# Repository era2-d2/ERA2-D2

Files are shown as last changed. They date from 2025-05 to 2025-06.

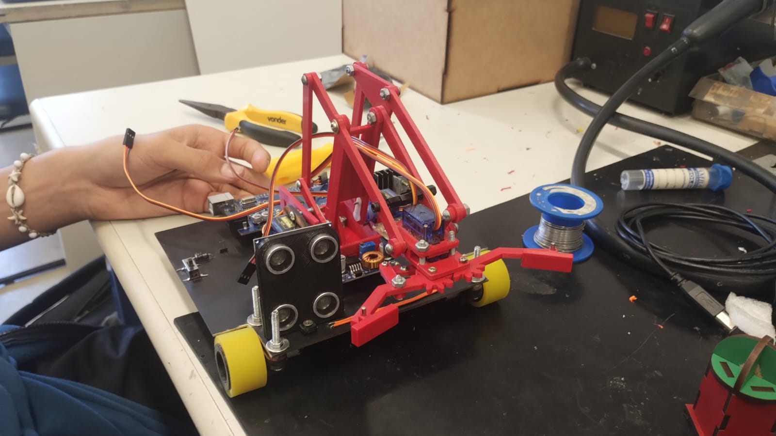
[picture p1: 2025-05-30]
Projeto/imagens/montagem.jpeg

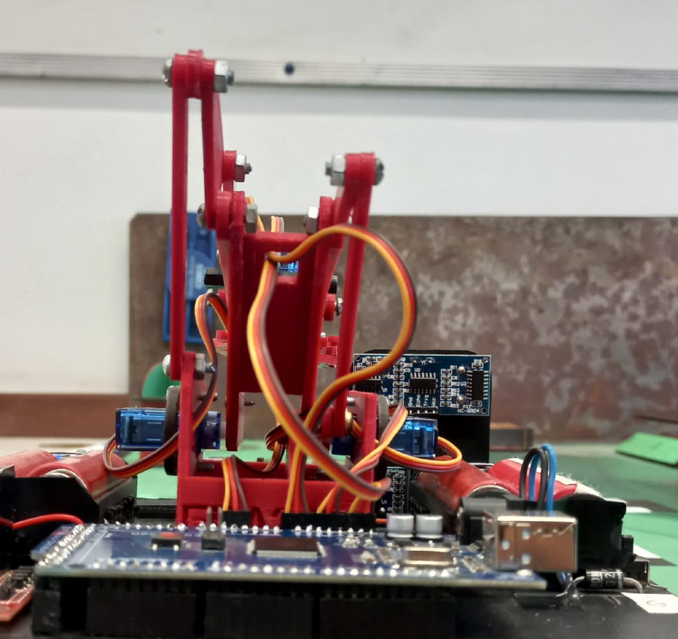
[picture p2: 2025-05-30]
Projeto/imagens/tras.jpeg

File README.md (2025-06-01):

# ERA2D2

A equipe **ERA2D2** é composta por estudantes do ensino médio do CEFET-MG, unidade Divinópolis, Minas Gerais. Desde o início de 2023, a equipe atua no âmbito do grupo **Estudos de Robótica e Automação (ERA)**, com o objetivo principal de participar da categoria High do Torneio Brasil de Robótica (TBR).

---

## Projeto Rios de Dados  
### Monitoramento em tempo real da qualidade da água

Este projeto foi desenvolvido para participação no Torneio Brasil de Robótica 2024 e tem como propósito contribuir para a preservação dos recursos hídricos e a promoção do desenvolvimento sustentável.

A plataforma criada possibilita a medição e o registro em tempo real de parâmetros essenciais da qualidade da água, tais como:

- pH  
- Turbidez  
- Níveis de oxigênio dissolvido  
- Temperatura  
- Condutividade elétrica  

Inspirada no 6º Objetivo de Desenvolvimento Sustentável das Nações Unidas (Água Potável e Saneamento), a solução emprega sensores para a coleta contínua de dados que podem ser acessados para análise e monitoramento. Tal sistema visa facilitar a tomada de decisões embasadas, o planejamento de ações corretivas e o envolvimento da comunidade local.

## Tecnologia e Engenharia

A subequipe responsável pela área de Tecnologia e Engenharia concentra seus esforços na concepção e construção de um robô autônomo capaz de atender às demandas do desafio prático proposto pelo Torneio Brasil de Robótica na categoria High (faixa etária de 15 a 19 anos).

A plataforma robótica é fundamentada em tecnologia Arduino, integrando sensores e atuadores que possibilitam o cumprimento das missões definidas pelo regulamento do TBR.

Além do desenvolvimento técnico, a equipe adota práticas colaborativas para garantir a integração eficiente das diversas áreas de conhecimento, assegurando a inovação e a eficácia dos projetos apresentados.

Essa abordagem contribui para a formação de profissionais técnicos qualificados, aptos a enfrentar desafios tecnológicos atuais e futuros, aplicando conhecimentos de forma prática e efetiva.

---

Imagens e vídeos relacionados ao projeto podem ser encontrados nas respectivas pastas do repositório.

---

## Estrutura do Projeto

O projeto está organizado da seguinte forma:

```
.
├── Mérito
│   ├── Códigos
│   ├── Impressões 3D
│   └── Monitoramento Rio Itapecerica
├── Projeto
│   ├── dados_monitoramento
│   ├── docs
│   ├── firmware
│   ├── hardware
│   └── README.md
└── Robô
├── Códigos
├── Skywalker 2.0
└── Skywalker 2.1
```

- **Mérito**: Contém códigos para as plataformas Arduino Mega e Nano, arquivos para impressões 3D e dados do monitoramento do Rio Itapecerica.  
- **Projeto**: Engloba dados do monitoramento, documentação técnica, firmware dos sistemas de monitoramento e robótico, além do hardware (modelos para impressão 3D, cortes em MDF, placas de circuito impresso, estruturas).  
- **Robô**: Abrange o desenvolvimento do robô autônomo, incluindo códigos-fonte, arquivos para fabricação e montagem, assim como versões do robô denominadas Skywalker 2.0 e 2.1.

---

## Outros Materiais

- [Tabela de Gastos](https://drive.google.com/drive/u/3/folders/1ZpHwaeWIHNITP21ojMcyqOMGcibrnDnj)
- [Relatório Sobre o Robô](https://drive.google.com/drive/u/3/folders/1UcZ1GNpwfR3S68cyZk29Z3KH6VcgLQlX)
- [Animações](https://drive.google.com/drive/folders/1Vy_ZClelRn55KMFLFU6ARa01si_wWNVY)

---

## Contato

- 🌐 Site: https://makesoft.net.br/era2d2
  
- 📧 E-mail: era2d2cefet@gmail.com

- 📷 Instagram: @era2d2

- 🎥 TikTok: @era2d2

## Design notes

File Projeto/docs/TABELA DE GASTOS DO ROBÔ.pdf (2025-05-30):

TABELAS DE GASTOS:
**Componentes referentes a sucata.
- | - | UNITÁRIO | UNITÁRIO | UNITÁRIO | UNITÁRIO
PRODUTO | QTE. | MERCADO LIVRE | ROBOCORE | ALIEXPRESS | MELHOR PREÇO
Placa de fenolite cobreada 20cm X 20cm | 1 | R$ 13,50 | - | R$ 16,21 | R$ 13,50
Sensor de distância VL53LXX-V2 | 1 | R$ 25,90 | - | R$ 8,69 | R$ 8,69
Esfera metálica de 18 mm de diâmetro | 1 | R$ 2,52 | - | R$ 3,03 | R$ 2,52
Arduino Mega 2560 | 1 | R$ 135,00 | R$ 112,10 | R$ 61,49 | R$ 61,49
Ponte H modelo L298N | 1 | R$ 11,66 | R$ 14,15 | R$ 7,41 | R$ 7,41
Módulo relé unitário 5V | 1 | R$ 11,99 | R$ 5,22 | R$ 6,99 | R$ 5,22
Regulador de tensão HW-286 | 1 | R$ 13,50 | - | R$ 13,47 | R$ 13,47
**LDR | 1 | R$ 1,06 | R$ 0,60 | R$ 0,20 | R$ 0,20
**Regulador de tensão LM7805cv | 1 | R$ 2,78 | - | R$ 0,30 | R$ 0,30
**Dissipador de calor pequeno | 1 | - | - | - | -
**Capacitor eletrolítico 0.1µF | 1 | R$ 1,13 | R$ 0,34 | R$ 0,23 | R$ 0,23

**Capacitor eletrolítico 0.33µF | 1 | R$ 0,20 | - | R$ 0,98 | R$ 0,20
**LEDs brancos de alto brilho | 2 | R$ 0,24 | R$ 0,47 | R$ 0,11 | R$ 0,11
**Chaves deslizantes | 2 | - | - | - | -
**Parafusos franceses pequenos | 2 | - | - | - | -
**Parafusos pequenos | 3 | R$ 0,08 | - | R$ 0,14 | R$ 0,08
**Espaçador sextavado | 6 | R$ 1,64 | R$ 1,42 | R$ 1,68 | R$ 1,42
**Diodos SK3G 0285 | 2 | R$ 2,21 | - | - | R$ 2,21
Motor DC N20 com caixa de redução 100/1 e encoder | 2 | - | - | R$ 45,00 | R$ 45,00
Par pneus de silicone Ø22mm | 1 | - | R$ 28,40 | - | R$ 28,40
Servomotores SG90 9 | 3 | R$ 12,21 | R$ 12,25 | R$ 6,99 | R$ 6,99
Parafusos 4 milímetros de diâmetro | 4 | R$ 0,68 | - | R$ 0,38 | R$ 0,38
Porcas 4 milímetros de diâmetro | 4 | R$ 0,68 | - | R$ 0,38 | R$ 0,38
** Baterias de lítio 18650 4.2V | 4 | R$ 29,90 | R$ 37,90 | R$ 23,23 | R$ 23,23

Tiras de velcro 73mm de comprimento | 4 | R$ 29,99 (3 metros) | - R$ 11,06 | (3 metros) | R$ 11,06
**Molas para contato de bateria | 4 | R$ 1,50 | R$ 1,58 | R$ 0,70 | R$ 0,70
Parafusos com 3 milímetros de diâmetro | 22 | R$ 0,25 | R$ 0,25 | R$ 0,15 | R$ 0,15
Porcas 3mm de diâmetro | 25 | R$ 0,25 | R$ 0,25 | R$ 0,15 | R$ 0,15
MELHOR PREÇO | 101 | - | - | - | R$ 382,87
TOTAL UTILIZANDO SUCATA | 101 | - | - | - | R$ 293,94
LOJAS | QTE. PRODUTOS (TOTAL = 28) | QTE. PEÇAS | PREÇO FINAL S/SUCATA | PREÇO FINAL C/SUCATA
MERCADO LIVRE | 23 | 93 | R$ 443,63 | R$ 297,88
ROBOCORE | 13 | 71 | R$ 376,69 | R$ 208,37
ALIEXPRESS | 23 | 93 | R$ 357,56 | R$ 249,41

PRODUTOS IMPRESSOS | QTE. | MakeSoft Solutions | PREÇO TOTAL
Garra | 1 | R$ 38,73 | R$ 38,73
Suporte para Ultrassônicos | 1 | R$ 2,19 | R$ 2,19
Suporte para Motores | 2 | R$ 0,75 | R$ 1,50
Cubo para Motores | 2 | R$ 1,95 | R$ 3,90
Suporte para Baterias | 2 | R$ 5,48 | R$ 10,96
Suporte LDR | 1 | R$ 0,68 | R$ 0,68
- | - | - | R$ 68,13

MELHOR PREÇO TOTAL FINAL S/SUCATA: R$ 440,83
MELHOR PREÇO TOTAL FINAL C/SUCATA: R$ 351,90

Considerações Finais:

Embora consideravelmente mais caras, as peças oferecidas pela Robocore e Mercado Livre são de melhor qualidade. Recomenda-se comprar a maioria das peças no Mercado Livre e, as que faltarem, na Aliexpress e Robocore. O valor final ficaria em R$474,24 com sucata e R$619,99 sem.

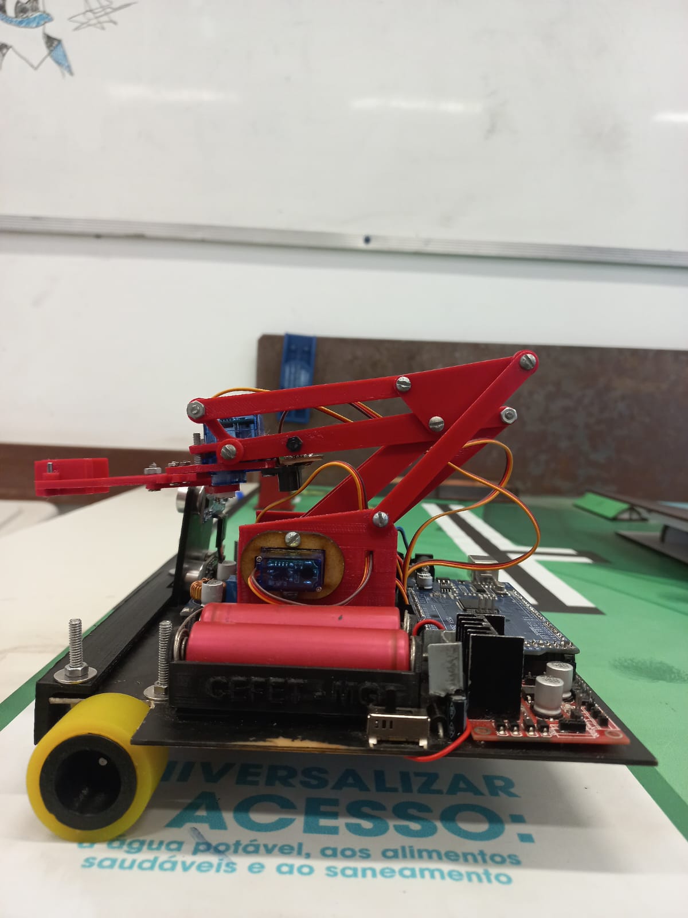
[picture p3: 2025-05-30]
Projeto/imagens/esquerda.jpeg

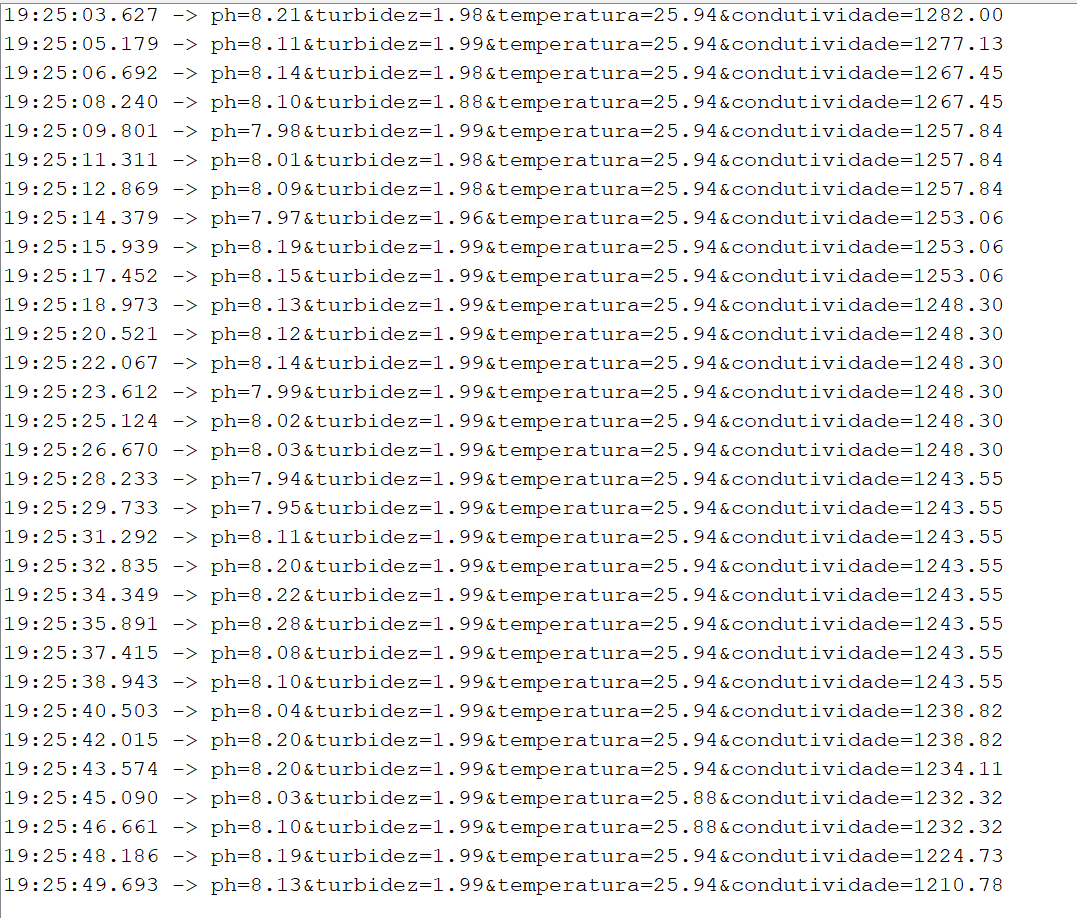
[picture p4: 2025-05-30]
Projeto/dados_monitoramento/ponto_3/Ponto 3.1.png

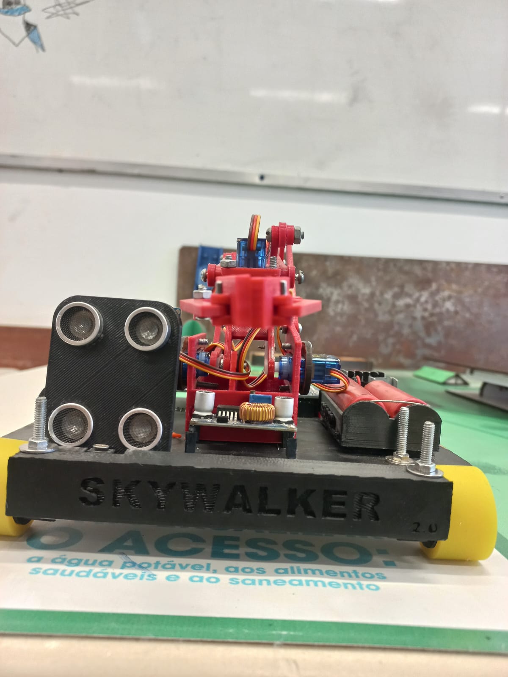
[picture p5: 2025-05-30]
Projeto/imagens/frente.jpeg

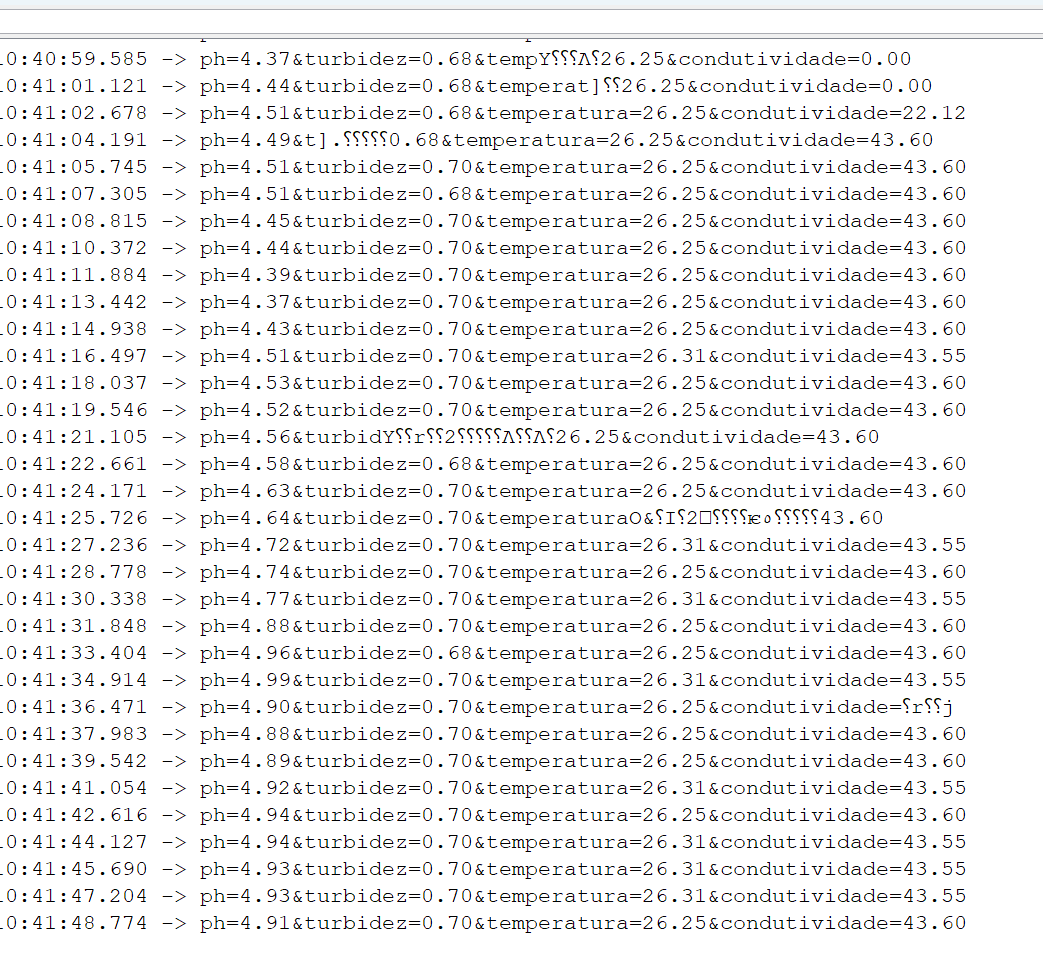
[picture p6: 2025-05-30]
Projeto/dados_monitoramento/ponto_2/Ponto 2.png

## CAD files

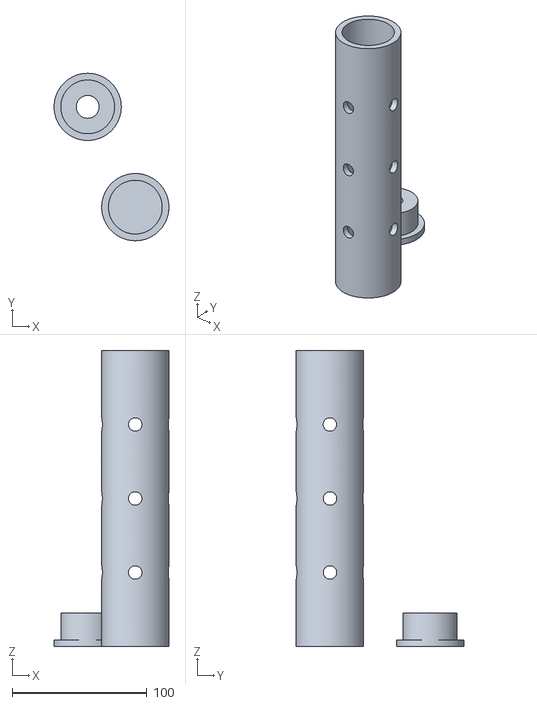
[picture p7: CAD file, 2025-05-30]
Mérito/Impressões 3D/Case - versão 1.stl
85.4 x 124.5 x 220.0

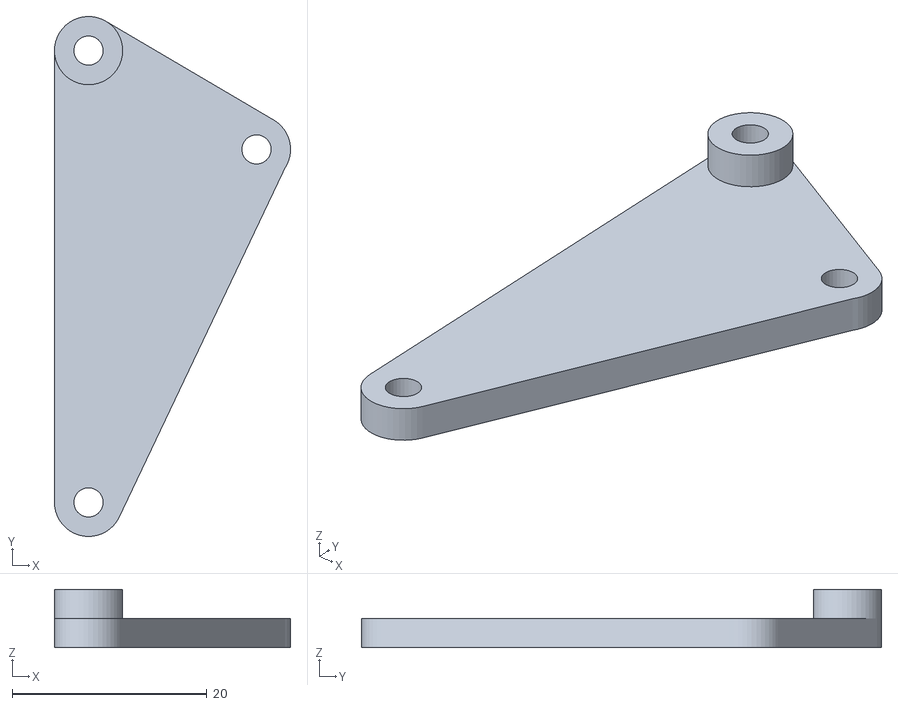
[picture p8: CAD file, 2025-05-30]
Projeto/hardware/3d_prints/robo/Braço Robótico Versão 1/Junta_01.stl
24.2 x 53.4 x 6.00

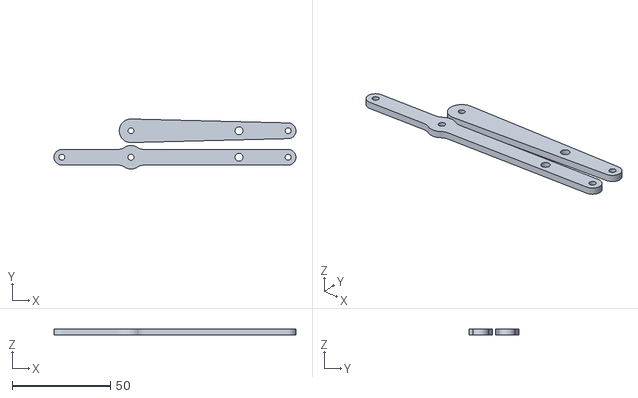
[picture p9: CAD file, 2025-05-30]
Projeto/hardware/3d_prints/robo/Garra pt2.stl
123.2 x 25.5 x 3.00

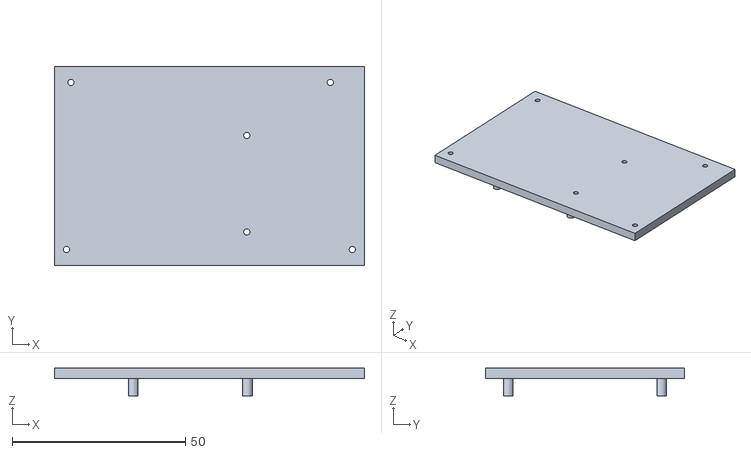
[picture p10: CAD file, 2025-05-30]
Projeto/hardware/3d_prints/robo/Impressões Diversas/Capa_ArduinoMega2560_v1.stl
89.5 x 57.3 x 8.00

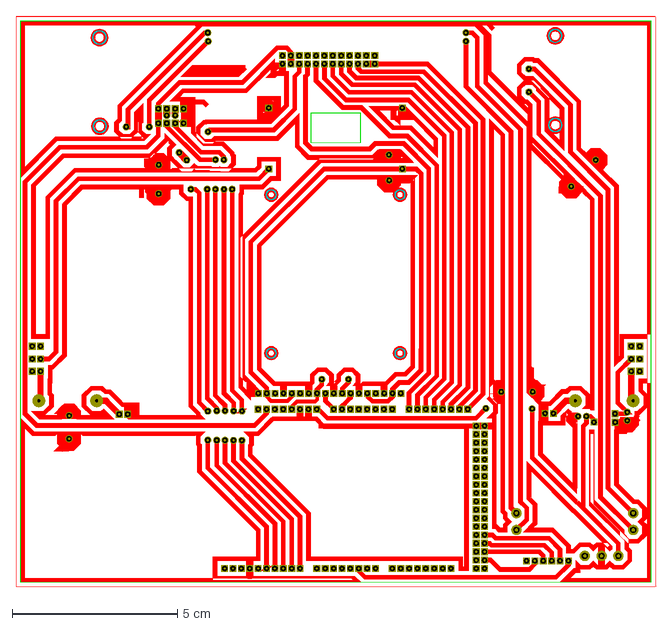
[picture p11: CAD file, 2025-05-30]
Projeto/hardware/pcb/robo/Skywalker 2.0/Estrutura Robo.DXF
19.4 x 17.3 cm

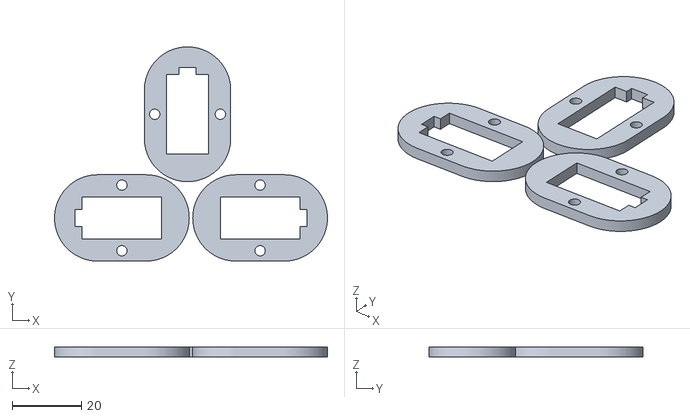
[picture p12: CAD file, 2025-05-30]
Projeto/hardware/3d_prints/robo/Braço Robótico Versão 1/Suporte_Servomotores.stl
79.0 x 62.0 x 3.00

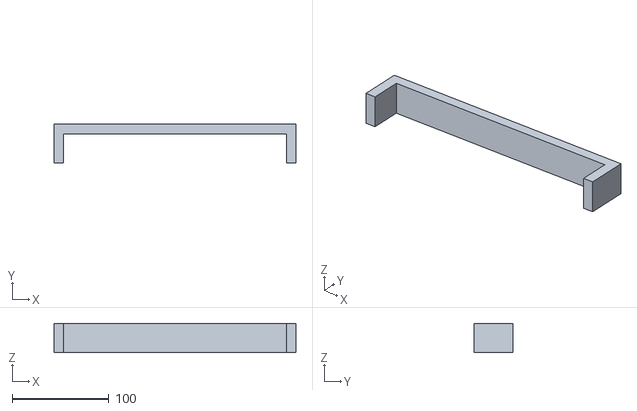
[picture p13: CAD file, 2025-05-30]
Projeto/hardware/3d_prints/robo/Impressões Diversas/Cola_Base.stl
250.0 x 40.0 x 30.0

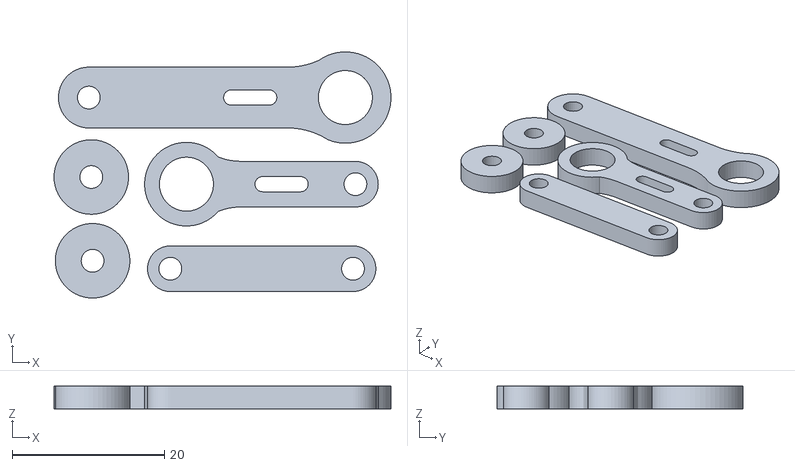
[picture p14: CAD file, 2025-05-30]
Projeto/hardware/3d_prints/robo/Braço Robótico Versão 1/Controle_Servomotores.stl
44.3 x 32.3 x 3.00

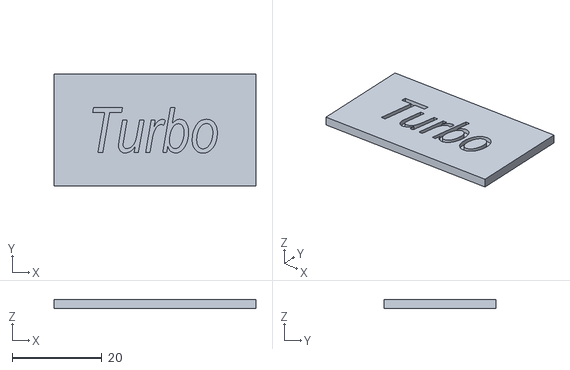
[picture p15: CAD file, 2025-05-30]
Projeto/hardware/3d_prints/robo/Impressões Diversas/TURBO.stl
45.0 x 25.0 x 2.00

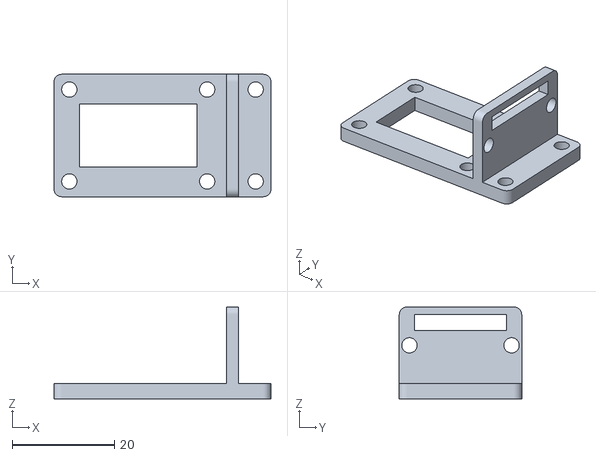
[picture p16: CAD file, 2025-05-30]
Projeto/hardware/3d_prints/robo/Braço Robótico Versão 1/Suporte_Servomotor_Garra_Inferior_Laser.stl
42.5 x 24.0 x 18.0

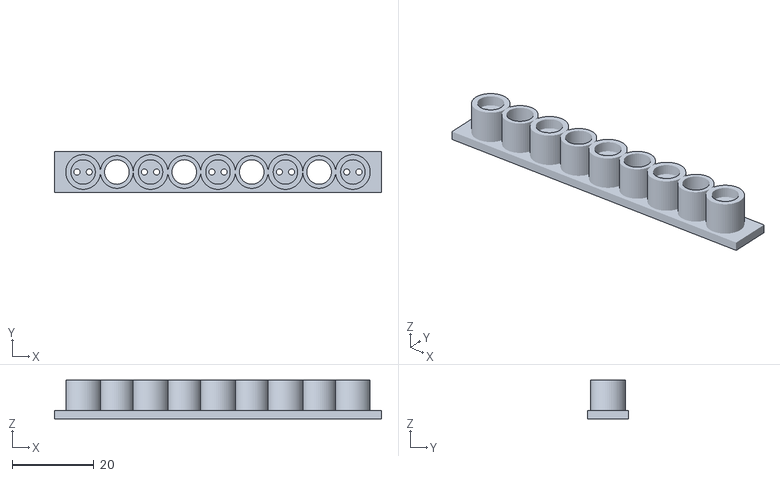
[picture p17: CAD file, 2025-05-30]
Projeto/hardware/3d_prints/robo/Impressões Diversas/Suporte_LDR_v9.stl
80.0 x 10.0 x 9.50

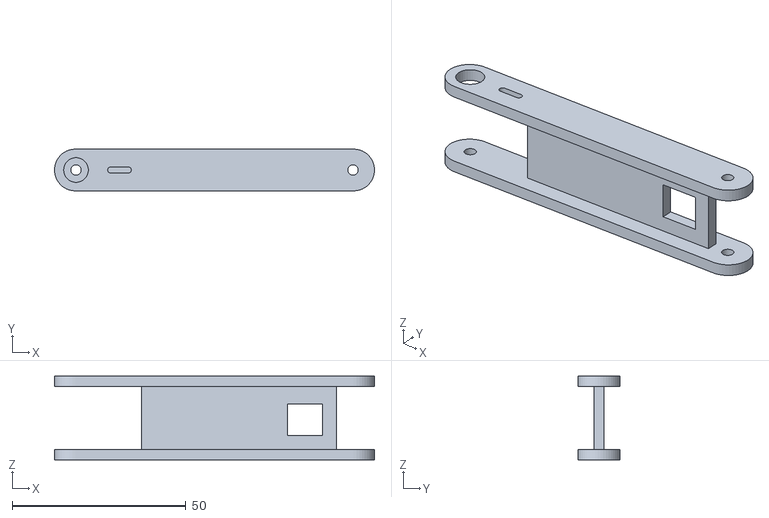
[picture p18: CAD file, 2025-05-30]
Projeto/hardware/3d_prints/robo/Braço Robótico Versão 1/Braço_Garra.stl
92.0 x 12.0 x 24.0

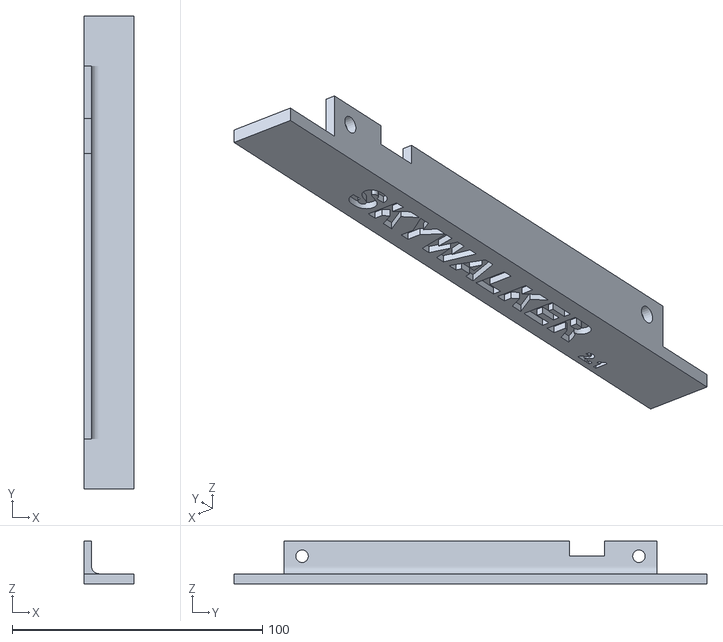
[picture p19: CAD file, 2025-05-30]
Projeto/hardware/3d_prints/robo/Impressões Diversas/SKYWALKER_2.1.stl
20.0 x 189.0 x 17.0

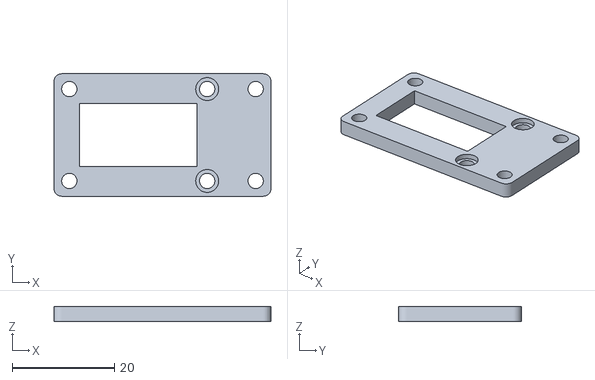
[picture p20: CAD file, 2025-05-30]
Projeto/hardware/3d_prints/robo/Braço Robótico Versão 1/Suporte_Servomotor_Garra_Inferior.stl
42.5 x 24.0 x 3.00

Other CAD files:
Projeto/hardware/3d_prints/robo/Impressões Diversas/Cola_LDR.stl
Projeto/hardware/3d_prints/robo/Braço Robótico Versão 1/Base_Garra.stl
Projeto/hardware/3d_prints/robo/Impressões Diversas/SKYWALKER_2.0.stl
Projeto/hardware/3d_prints/robo/Braço Robótico Versão 1/Garra.stl
Projeto/hardware/3d_prints/robo/Braço Robótico Versão 1/Mecanização_Braço.stl
Projeto/hardware/3d_prints/robo/Braço Robótico Versão 1/Ponta_Garra.stl
Projeto/hardware/3d_prints/robo/Braço Robótico Versão 1/Suporte_Servomotor_Garra.stl
Projeto/hardware/3d_prints/robo/Impressões Diversas/Base_Ultrassônico.stl
Projeto/hardware/3d_prints/robo/Impressões Diversas/Bolinha_v3.stl
Projeto/hardware/3d_prints/robo/Impressões Diversas/PINO.stl
Projeto/hardware/3d_prints/robo/Impressões Diversas/Suporte_Bateria.stl

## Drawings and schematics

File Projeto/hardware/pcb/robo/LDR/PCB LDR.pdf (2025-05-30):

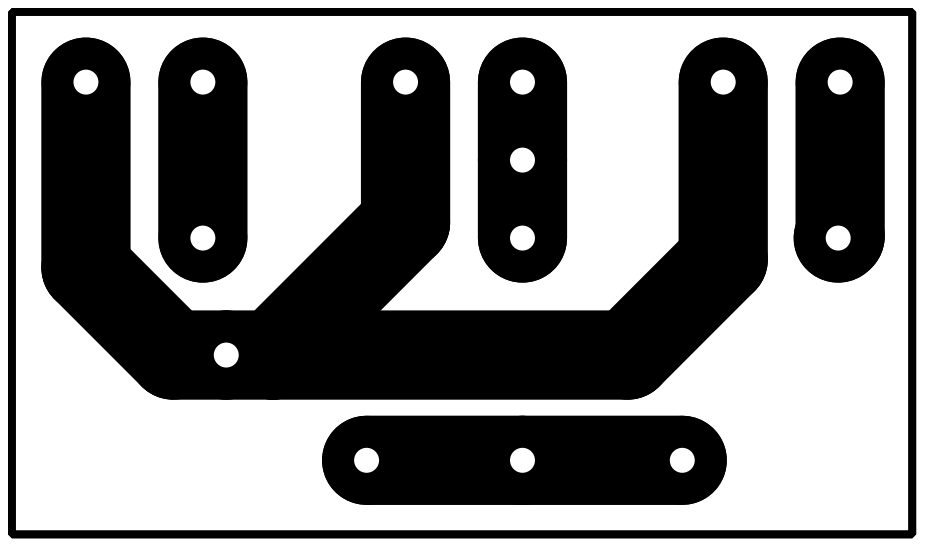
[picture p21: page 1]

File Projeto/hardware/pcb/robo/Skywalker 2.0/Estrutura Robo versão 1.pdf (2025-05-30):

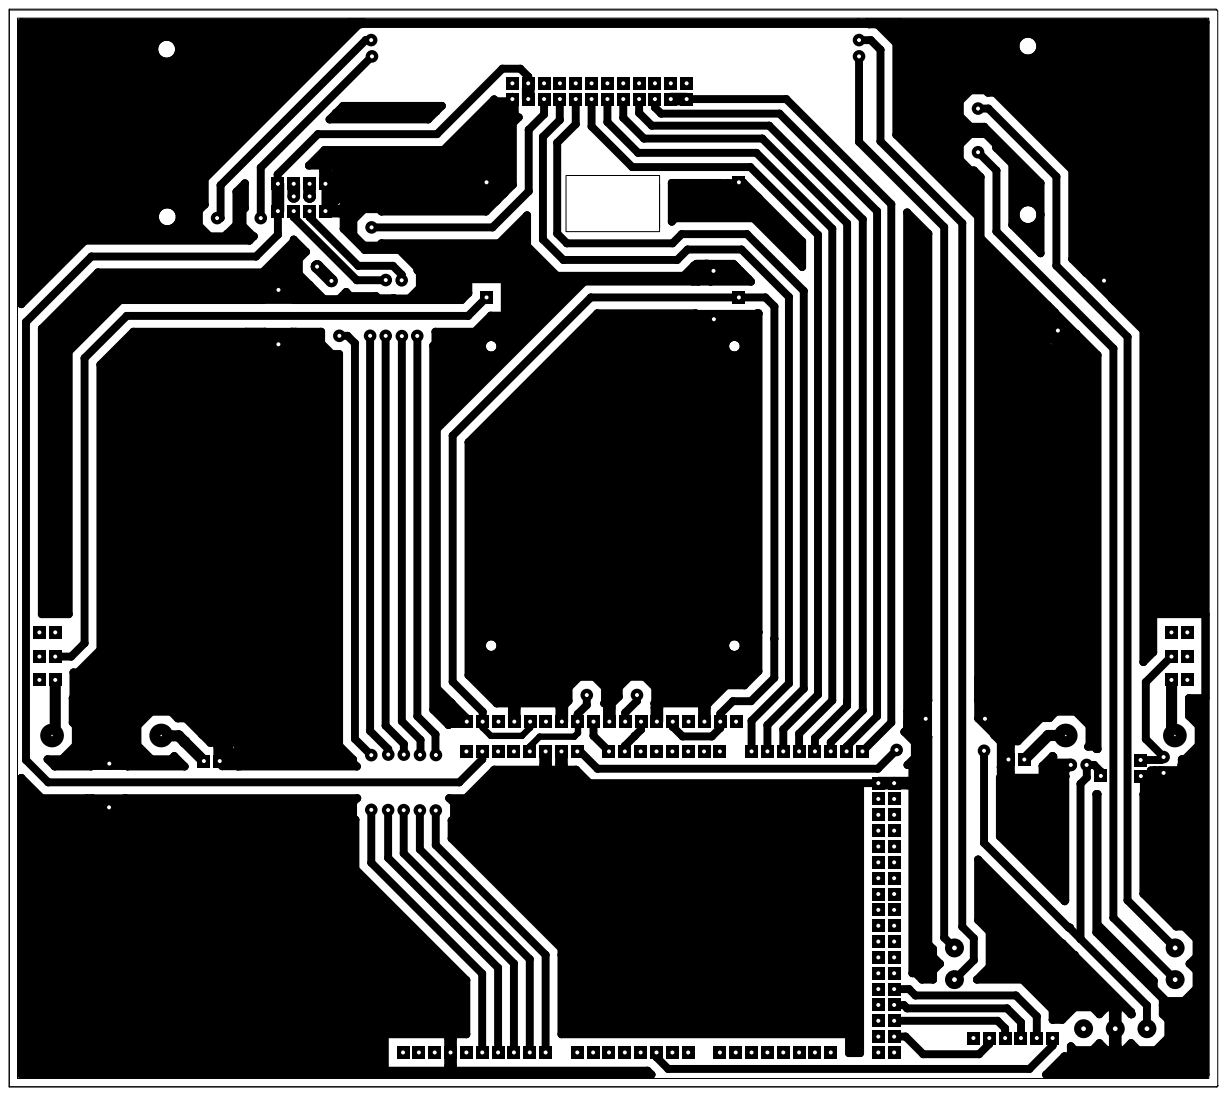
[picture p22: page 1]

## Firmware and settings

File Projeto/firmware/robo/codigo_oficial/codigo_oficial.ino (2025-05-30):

// Bibliotecas.
#include <VL53L0X.h>
#include <EEPROM.h>
#include <HCSR04.h>
#include <Servo.h>
#include <Wire.h>
//#include <StarWars.h>

// Motores.
#define mEa 29
#define mEb 27
#define mDa 25
#define mDb 23
#define mEv 2
#define mDv 3

// Constantes.
#define tempoDir 8.1111 // original 8.1111   //02-08: 7.73  // 07-08: 7.72  // 09-08: 8.36
#define tempoEsq 8.3625 // original 8.3625   //02-08: 8.005  // 07-08: 8.36  // 09-08: 7.95
#define tempoReto 0.01890359

#define velE 240
#define velD 255

#define porcentagemMotor 1.1
#define porcentagemEsquerda 1.03
#define porcentagemDireita 1.06
#define debug 1.02

// Sensor de cor.
#define sc A0
bool CORPRETA;
bool leituraCorPreta;
byte contagemDerrubados = 0;

// Mínimos e Máximos de leitura da cor vermelha.
int CORVERMELHAMin = 4 * EEPROM.read(5);
int CORVERMELHAMax = 4 * EEPROM.read(6);

// Calibração de cores.
#define PRETO 1
#define BRANCO 0

// Garra.
Servo servo1; // 60 a 140 graus  - graus, mais pra tras
Servo servo2; // 50 a 140 graus  - graus, mais alto
Servo servo3; // 180 a 90 graus  - graus, garra fechada

byte i = 0;

// Laser.
VL53L0X laser;
unsigned long distanciaLaser;

// Ultrassônico.
#define trig1 11
#define trig2 10
#define echo1 8
#define echo2 9

UltraSonicDistanceSensor us1(trig1, echo1); // (Trig, Echo)
UltraSonicDistanceSensor us2(trig2, echo2);

unsigned long distancia1;
unsigned long distancia2;

bool arvoreP = false;
bool arvoreG = false;

// Funções dos Motores.
void Para(int para)
{

    digitalWrite(mEa, LOW);
    digitalWrite(mEb, LOW);
    analogWrite(mEv, 0);
    digitalWrite(mDa, LOW);
    digitalWrite(mDb, LOW);
    analogWrite(mDv, 0);
    delay(para);
}

// Tempo.
float Distancia(float distancia)
{
    distancia = (float)(distancia * 1.0238 + 0.486);
    float tempo = (float)(distancia / tempoReto);
    return tempo;
}

void Direcao(float tempo, bool frente = true)
{

    bool a = frente ? true : false;
    bool b = frente ? false : true;

    digitalWrite(mEa, a);
    digitalWrite(mEb, b);
    analogWrite(mEv, velE);

    digitalWrite(mDa, a);
    digitalWrite(mDb, b);
    analogWrite(mDv, velD);
    delay(tempo * porcentagemMotor);
    Para(100);
}

void Gira(float angulo, bool esquerda = true)
{

    bool a = esquerda ? false : true;
    bool b = esquerda ? true : false;
    float tempo = esquerda ? (angulo * tempoEsq * porcentagemEsquerda) : (angulo * tempoDir * porcentagemDireita);

    digitalWrite(mEa, a);
    digitalWrite(mEb, b);
    analogWrite(mEv, velE);

    digitalWrite(mDa, b);
    digitalWrite(mDb, a);
    analogWrite(mDv, velD);
    delay(tempo);
    Para(100);
}

// Funções Sensor de Cor.
void SensorCor()
{
    if (analogRead(sc) > CORVERMELHAMax)
    {
        CORPRETA = 1;
    }
    else
    {
        CORPRETA = 0;
    }
}

void SensorCorAux()
{
    if (analogRead(sc) > CORVERMELHAMax)
    {
        leituraCorPreta = 1;
    }
    else
    {
        leituraCorPreta = 0;
    }
}

// Garra.
void Inicial()
{
    int v1 = servo1.read();
    int v2 = servo2.read();

    // Ajusta o servo1 para 145º.
    if (v1 < 145)
    {
        for (int i = v1; i <= 145; i++)
        {
            servo1.write(i);
            delay(12);
        }
    }
    else if (v1 > 145)
    {
        for (int i = v1; i >= 145; i--)
        {
            servo1.write(i);
            delay(12);
        }
    }

    // Ajusta o servo2 para 70º.
    if (v2 < 70)
    {
        for (int i = v2; i <= 70; i++)
        {
            servo2.write(i);
            delay(12);
        }
    }
    else if (v2 > 70)
    {
        for (int i = v2; i >= 70; i--)
        {
            servo2.write(i);
            delay(12);
        }
    }

    servo3.write(180);
}

void ArvoreGrande()
{
    for (i = 145; i >= 45; i--)
    { // Servo1: 35 para a árvore pequena e 55 para a árvore grande.
        servo1.write(i);
        delay(12);
    }

    for (i = 70; i <= 130; i++)
    {
        servo2.write(i);
        delay(12);
    }
}

void ArvorePequena()
{
    for (i = 145; i >= 30; i--)
    { // Servo1: 35 para a árvore pequena e 55 para a árvore grande.
        servo1.write(i);
        delay(12);
    }

    for (i = 70; i <= 130; i++)
    {
        servo2.write(i);
        delay(12);
        // Não fique torto por favor, te amamos por isso ❤.
    }
}

// Laser.
bool Laser()
{
  distanciaLaser = laser.readRangeContinuousMillimeters() - 25; // 25 é o erro do sensor.
  distanciaLaser < 100 ? arvoreG = 1 : arvoreG = 0;
}

// Ultrassônico.
bool Ultrassonico()
{
    // distancia1 = us1.measureDistanceCm();
    distancia2 = us2.measureDistanceCm();

    if (distancia2 < 10.0)
    {
        arvoreG = true;
    }
    else
    {
        arvoreG = false;
    }
    return arvoreG;
}

// Missão da Cor.
void Turbo(int tempo)
{

    digitalWrite(4, LOW);
    digitalWrite(mEa, HIGH);
    digitalWrite(mEb, LOW);
    analogWrite(mEv, velE);
    digitalWrite(mDa, HIGH);
    digitalWrite(mDb, LOW);
    analogWrite(mDv, velD);
    delay(tempo);
    digitalWrite(4, HIGH);
}

void Rampa(int tempo)
{

    for (i = 145; i >= 48; i--)
    { // Servo1: 35 para a árvore pequena e 55 para a árvore grande.
        servo1.write(i);
        delay(12);
    }

    for (i = 70; i >= 65; i--)
    { // Servo1: 35 para a árvore pequena e 55 para a árvore grande.
        servo2.write(i);
        delay(12);
    }

    servo3.write(85);

    Turbo(tempo);

    tempo = 2000;

    for (i = 48; i >= 20; i--)
    { // Servo1: 35 para a árvore pequena e 55 para a árvore grande.
        servo1.write(i);
        delay(12);

        Turbo(tempo);
        break;
    }
}

void AbaixaRampa()
{

    for (i = 145; i >= 70; i--)
    {
        servo1.write(i);
        delay(12);
    }

    for (i = 70; i <= 180; i++)
    {
        servo2.write(i);
        delay(12);
    }

    for (i = 70; i >= 50; i--)
    {
        servo1.write(i);
        delay(12);
    }
}

void Cor()
{

    for (i = 30; i <= 60; i++)
    {
        servo1.write(i);
        delay(12);
    }
    servo2.write(65);
}

void setup()
{

    // Motores.
    pinMode(mEa, OUTPUT);
    pinMode(mEb, OUTPUT);
    pinMode(mDa, OUTPUT);
    pinMode(mDb, OUTPUT);
    pinMode(mEv, OUTPUT);
    pinMode(mDv, OUTPUT);
    pinMode(4, OUTPUT);

    // Sensor de Cor.
    pinMode(sc, INPUT);

    // Servomotores.
    servo1.attach(5);
    servo2.attach(6);
    servo3.attach(7);

    // Ultrassônicos.
    pinMode(trig1, OUTPUT);
    pinMode(trig2, OUTPUT);
    pinMode(echo1, INPUT);
    pinMode(echo2, INPUT);

    // Inicializações.
    digitalWrite(4, HIGH);
    Inicial();

    // StarWars Theme
    // ImperialMarch march(45, 108);

    // Laser.
//    Wire.begin();
//    
//    laser.setTimeout(500);
//    
//    if (!laser.init()) while (true);
//
//    // Inicia o modo contínuo consecutivo (Lê o mais rápido possível).
//    laser.startContinuous();
  
    //Para usar o modo de tempo contínuo, forneça um período entre as medições em millissegundos laser.startContinuous(100).
}

void loop()
{

    // Primeira parte.

    Gira(90 * debug);         // Esquerda
    Direcao(Distancia(53.5)); // Frente
    Gira(90);                 // Esquerda
    Direcao(Distancia(11.5)); // Frente

    if (Ultrassonico())
    {

        Direcao(Distancia(12), false); // Trás
        Gira(90, false);               // Direita
        Direcao(Distancia(6));         // Frente
        Gira(90);                      // Esquerda
        ArvoreGrande();                // ARVORE GRANDE.
        Direcao(Distancia(6.5));       // Frente

        for (i = 180; i >= 80; i--)
        {
            servo3.write(i);
            delay(12);
        }

        for (i = 45; i <= 110; i++)
        {
            servo1.write(i);
            delay(12);
        }

        for (i = 130; i >= 90; i--)
        {
            servo2.write(i);
            delay(12);
        }

        Direcao(Distancia(6), false); // Trás
        Gira(90, false);              // Direita
        Direcao(Distancia(5));        // Frente
        Gira(90, false);              // Direita
        Direcao(Distancia(5.5));      // Frente
        Gira(91);                     // Esquerda
        Direcao(Distancia(16));       // Frente

        for (i = 110; i <= 120; i++)
        {
            servo1.write(i);
            delay(12);
        }

        servo3.write(180);

        // Pegar próxima árvore.

        Direcao(Distancia(8), false); // Trás
        Gira(90);                     // Esquerda
        Direcao(Distancia(18));       // Frente
        Gira(20, false);              // Direita

        for (i = 90; i <= 135; i++)
        {
            servo2.write(i);
            delay(12);
        }

        for (i = 110; i >= 32; i--)
        {
            servo1.write(i);
            delay(12);
        }

        for (i = 180; i >= 80; i--)
        {
            servo3.write(i);
            delay(8);
        }

        for (i = 32; i <= 115; i++)
        {
            servo1.write(i);
            delay(12);
        }

        Direcao(Distancia(4), false); // Trás
        Gira(60, false);              // Direita
        Direcao(Distancia(16));       // Frente
        servo3.write(180);

        // Árvore pequena.
    }
    else
    {

        Direcao(Distancia(12), false); // Trás
        Gira(90, false);               // Direita
        Direcao(Distancia(6));         // Frente
        Gira(90);                      // Esquerda
        ArvorePequena();
        Direcao(Distancia(6)); // Frente

        for (i = 180; i >= 80; i--)
        {
            servo3.write(i);
            delay(12);
        }

        for (i = 45; i <= 100; i++)
        {
            servo1.write(i);
            delay(12);
        }

        servo1.write(100);

        Direcao(Distancia(4), false); // Trás
        Gira(90, false);              // Direita
        Direcao(Distancia(20));       // Frente

        for (i = 120; i <= 120; i++)
        {
            servo1.write(i);
            delay(12);
        }

        for (i = 130; i <= 130; i++)
        {
            servo2.write(i);
            delay(12);
        }

        servo3.write(180);

        // Pegar próxima árvore.
        Direcao(Distancia(8.5), false); // Trás
        Gira(60);                       // Esquerda

        for (i = 130; i >= 100; i--)
        {
            servo2.write(i);
            delay(12);
        }

        for (i = 120; i >= 45; i--)
        {
            servo1.write(i);
            delay(12);
        }

        Direcao(Distancia(8)); // Frente

        for (i = 180; i >= 80; i--)
        {
            servo3.write(i);
            delay(8);
        }

        for (i = 45; i <= 110; i++)
        {
            servo1.write(i);
            delay(12);
        }

        for (i = 100; i >= 55; i--)
        {
            servo2.write(i);
            delay(12);
        }

        Direcao(Distancia(9), false); // Trás
        Gira(60, false);              // Direita
        Direcao(Distancia(3));        // Frente
        Gira(90, false);              // Direita
        Direcao(Distancia(8));        // Frente
        Gira(90);                     // Esquerda
        Direcao(Distancia(14));       // Frente

        for (i = 60; i <= 110; i++)
        {
            servo2.write(i);
            delay(12);
        }

        for (i = 110; i >= 105; i--)
        {
            servo1.write(i);
            delay(12);
        }

        servo3.write(180);
        Direcao(Distancia(8), false);  // Trás
        Gira(89, false);               // Direita
        Direcao(Distancia(19), false); // Trás
        Gira(92);                      // Esquerda
    }

    Direcao(Distancia(62), false); // Trás
    // march.playMelody();
    delay(120000);

    // SEGUNDA MISSÃO

    Direcao(Distancia(34.2)); // Frente
    Gira(92, false);          // Direita
    Direcao(Distancia(20));   // Frente
    Rampa(650);
    Gira(3);                // Esquerda
    Direcao(Distancia(35)); // Frente

    Cor();
    SensorCor();

    for (i = 60; i <= 80; i++)
    {
        servo1.write(i);
        delay(10);
    }

    for (i = 65; i >= 55; i--)
    {
        servo2.write(i);
        delay(10);
    }

    for (i = 180; i >= 90; i--)
    {
        servo3.write(i);
        delay(5);
    }

    Direcao(Distancia(32), false); // Trás
    Gira(88.5, false);             // Direita
    Direcao(Distancia(32));        // Frente

    for (int y = 0; y < 4; y++)
    {

        SensorCorAux();

        if (leituraCorPreta == CORPRETA)
        {

            if (contagemDerrubados == 4)
            {
                break;
            }

            // Alteramos durante o ensaio
            Direcao(Distancia(10), false); // Trás
            Gira(35, false);               // Direita

            for (i = 80; i >= 40; i--)
            {
                servo1.write(i);
                delay(10);
            }

            Gira(40); // Esquerda
            contagemDerrubados++;

            for (i = 40; i <= 80; i++)
            {
                servo1.write(i);
                delay(10);
            }

            if (y == 3)
            {
                break;
            }
        }
        else
        {

            if (y == 3)
            {
                break;
            }
            Direcao(Distancia(10), false); // Trás
        }

        if (contagemDerrubados >= 4)
        {
            break;
        }

        Gira(94);                 // Esquerda
        Direcao(Distancia(25.5)); // Frente
        Gira(90, false);          // Direita
        Direcao(Distancia(11.2)); // Frente
    }

    if (contagemDerrubados < 4)
    {

        if (leituraCorPreta == CORPRETA)
        {
            Direcao(Distancia(18), false); // Trás
        }
        else
        {
            Direcao(Distancia(25), false); // Trás
        }

        Gira(89, false);        // Direita
        Direcao(Distancia(40)); // Frente

        // Outro lado (otherside).
        Direcao(Distancia(27), false); // Trás
        Gira(90, false);               // Direita
        Direcao(Distancia(33));        // Frente

        for (int y = 0; y < 4; y++)
        {

            if (contagemDerrubados == 4)
            {
                break;
            }

            SensorCorAux();

            if (leituraCorPreta == CORPRETA)
            {

                if (contagemDerrubados == 4)
                {
                    break;
                }

                Direcao(Distancia(9), false); // Trás
                Gira(40);                     // Esquerda

                for (i = 80; i >= 40; i--)
                {
                    servo1.write(i);
                    delay(10);
                }

                Gira(35, false); // Direita
                contagemDerrubados++;

                for (i = 40; i <= 80; i++)
                {
                    servo1.write(i);
                    delay(10);
                }

                if (y == 3)
                {
                    break;
                }
            }
            else
            {

                if (y == 3)
                {
                    break;
                }

                Direcao(Distancia(10), false); // Trás
            }

            if (contagemDerrubados >= 4)
            {
                break;
            }

            Gira(95);                 // Esquerda
            Direcao(Distancia(26.8)); // Frente
            Gira(89, false);          // Direita
            Direcao(Distancia(12));   // Frente
        }
    }
    else
    {
        // march.playMelody();
        delay(1000000);
    }
    // march.playMelody();
    delay(1000000);
}

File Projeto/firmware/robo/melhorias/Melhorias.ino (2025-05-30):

// Bibliotecas.
//#include <StarWars.h> // Música StarWars.
#include <VL53L0X.h>  // Sensor Laser.
#include <EEPROM.h>   // Memória EEPROM.
#include <HCSR04.h>   // Ultrassônico.
#include <Servo.h>    // Servomotores.
#include <Wire.h>     // Protocolo I2C.

// Pinos dos Motores.
#define mEa 29 // Pino Digital.
#define mEb 27 // Pino Digital.
#define mDa 25 // Pino Digital.
#define mDb 23 // Pino Digital.
#define mEv 2  // Pino Digital PWM.
#define mDv 3  // Pino Digital PWM.

// Pinos dos Encoders.
#define pinAD 18 // Canal A.
#define pinAE 19 // Canal A.
//#define pinBD  // Canal B.
//#define pinBD  // Canal B.

// Constantes dos Motores.
#define velE 255 // 100% de velocidade no Motor Esquerdo.
#define velD 217 // 85% de velocidade no Motor Direito.
const float debugEnc = 0.968; // Erro do encoder. Aumentar o valor (> 0.9) vai pra esquerda.
// ❤☺

const double perimetro = 10.68141502; // Perímetro da roda.
const double circunferencia = 54.35393641; // Circuinferência do robô (diâmetro = distância entre eixo das rodas).

// Parâmetros PID.
const double Kp = 5.8;  // 6    Constante Proporcional.
const double Ki = 0.6;  // 0.6  Constante Integrativa.
const double Kd = 0.7;  // 0.75 Constante Derivativa.
const double Tm = 0.03; // 0.03 // Tempo de amostragem média entre leituras.

double erro, erro1 = 0, erro2 = 0;
double PWME, PWMD, PWME1 = velE, PWMD1 = velD;

double distanciaE = 0, distanciaD = 0, distanciaT = 0;
unsigned long primeiroMillis;

volatile long pulsosE = 0, pulsosD = 0;

// Dados importantes
const float distanciaPoluentes = 25.5; // Valor arbitário, é necessário alterá-lo
int numPoluente = 0;

//---------------------------------------------------------------------------------ENCODER-------------------------------------------------------------------------------//
void ContadorEsq() {
  pulsosE++;
}
void ContadorDir() {
  pulsosD++;
}
void PIDEncoder() {

  if ((millis() - primeiroMillis) >= (Tm * 1000)) {
    noInterrupts();
    distanciaE = (double)(perimetro * pulsosE * debugEnc) / 1400;
    distanciaD = (double)(perimetro * pulsosD) / 1400;
    distanciaT = distanciaT + (double)(perimetro * pulsosE) / 1400;
    interrupts();

    pulsosD = pulsosE = 0;
    primeiroMillis = millis();
  }

  erro = distanciaD - distanciaE;

  //---------SATURAR PWM DE ENTRADA----------//
  if (PWME1 > 255) PWME1 = 255;
  if (PWME1 < 110) PWME1 = 110;

  if (PWMD1 > 255) PWMD1 = 255;
  if (PWMD1 < 110) PWMD1 = 110;

  //--------------CALCULO PID----------------//
  PWME = PWME1 + (double)((Kp + Kd / Tm) * erro + (Ki * Tm - 2 * Kd / Tm) * erro1 + (Kd / Tm) * erro2); // Retirou-se -Kp de (-Kp + Ki*Tm -2*Kd/Tm).
  PWMD = PWMD1 + (double)((Kp + Kd / Tm) * (-1 * erro) + (Ki * Tm - 2 * Kd / Tm) * (-1 * erro1) + (Kd / Tm) * (-1 * erro2)); // O erro direito é sempre o oposto do esquerdo.
  PWME1 = PWME;
  PWMD1 = PWMD;
  erro2 = erro1;
  erro1 = erro;

  //----------SATURAR PWM DE SAÍDA-----------//
  if (PWME > 255) PWME = 255;
  if (PWME < 110) PWME = 110;

  if (PWMD > 255) PWMD = 255;
  if (PWMD < 110) PWMD = 110;

  //------------COMANDO MOTORES--------------//
  analogWrite(mEv, PWME);
  analogWrite(mDv, PWMD);
}

//----------------------------------------------------------------------------------GARRA--------------------------------------------------------------------------------//
Servo servo1; // 30 a 145 graus  - graus, mais pra tras.
Servo servo2; // 50 a 140 graus  - graus, mais alto.
Servo servo3; // 180 a 85 graus  - graus, garra fechada.

byte ultimoEstadoX = 0, ultimoEstadoY = 0, ultimoEstadoGarra;

// Funções da Garra.
void Garra(int x, int y, bool fechada = false) {
  if (x <= 30) x = 30;
  if (x >= 145) x = 145;

  // Servo1.
  if (ultimoEstadoX > x) {
    for (byte i = ultimoEstadoX; i >= x; i--) {
      servo1.write(i);
      delay(10);
    }
  } else if (ultimoEstadoX < x) {
    for (byte i = ultimoEstadoX; i <= x; i++) {
      servo1.write(i);
      delay(10);
    }
  }

  // Servo2.
  if (ultimoEstadoY > y) {
    for (byte i = ultimoEstadoY; i >= y; i--) {
      servo2.write(i);
      delay(12);
    }
  } else if (ultimoEstadoY < y) {
    for (byte i = ultimoEstadoY; i <= y; i++) {
      servo2.write(i);
      delay(12);
    }
  }

  // Servo3.
  if (fechada == true) {
    if (ultimoEstadoGarra = true) ultimoEstadoGarra = 90;
    for (byte i = ultimoEstadoGarra; i >= 90; i--) {
      servo3.write(i);
      delay(10);
    }
  }
  else  servo3.write(180);
  ultimoEstadoGarra = fechada;
  ultimoEstadoX = x;
  ultimoEstadoY = y;
}

void Inicial() {
  ultimoEstadoX = servo1.read();
  ultimoEstadoY = servo2.read();

  Garra(145, 70); // Posição inicial: Servo1 em 145º e Servo2 em 60º, garra aberta.
}

void LerArvore() {
  Garra(90, 110);  // Altura ideal para fazer a leitura das alturas das árvores.
}
void ArvoreGrande() {
  Garra(70, 135);  // Altura ideal para pegar a árvore grande.
}
void ArvorePequena() {
  Garra(60, 130);  // Altura ideal para pegar a árvore pequena.
}

//------------------------------------------------------------------------------SENSOR DE COR----------------------------------------------------------------------------//
#define sc A0 // Pino do Sensor de Cor.

bool CORPRETA;
bool leituraCorPreta;
int contagemDerrubados = 0;

// Mínimos e Máximos de leitura da cor vermelha.
unsigned int CORVERMELHAMin;
unsigned int CORVERMELHAMax;

// Funções Sensor de Cor.
void SensorCor() {
  if (analogRead(sc) > CORVERMELHAMax) CORPRETA = 1;
  else CORPRETA = 0;
}

void SensorCorAux() {
  if (analogRead(sc) > CORVERMELHAMax) leituraCorPreta = 1;
  else leituraCorPreta = 0;
}

//----------------------------------------------------------------------------------LASER--------------------------------------------------------------------------------//
float distanciaUs1 = 0;   // Armazena a leitura de distância do Ultrassônico 1.
float distanciaUs2 = 0;   // Armazena a leitura de distância do Ultrassônico 2.
float distanciaLaser = 0; // Armazena a leitura de distância do Laser.

bool arvoreG; // Árvore Grande, verdadeira ou falsa.

VL53L0X laser; // Declara o Laser 1.

// Função do Laser.
bool Laser() {

  distanciaLaser = (laser.readRangeContinuousMillimeters() - 20); // 20 é o erro do sensor.

  if (distanciaLaser <= 130.0) arvoreG = true;
  else arvoreG = false;

  Serial.print(distanciaLaser);
  Serial.print("     ");
  Serial.println(arvoreG);

  return arvoreG;
}

//------------------------------------------------------------------------------ULTRASSÔNICO-----------------------------------------------------------------------------//
// Pinos dos Ultrassônicos.
#define trig1 11 // Pino Digital.
#define trig2 10 // Pino Digital.
#define echo1 8  // Pino Digital.
#define echo2 9  // Pino Digital.

UltraSonicDistanceSensor us1(trig1, echo1); // Declara o Ultrassônico 1.
UltraSonicDistanceSensor us2(trig2, echo2); // Declara o Ultrassônico 2.
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
